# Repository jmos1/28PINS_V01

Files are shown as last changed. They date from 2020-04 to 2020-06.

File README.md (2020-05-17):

# 28Pins(Arduino) Project
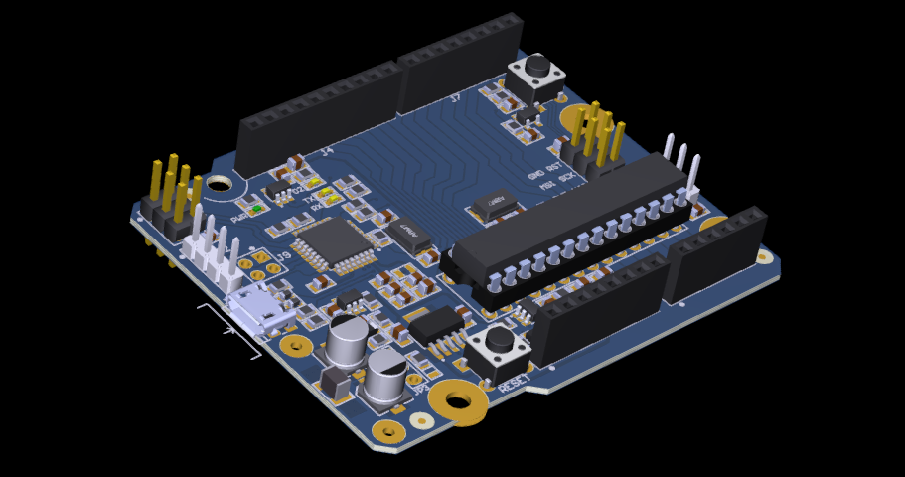
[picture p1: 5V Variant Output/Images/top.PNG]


### Summary: ###
  This project is one of two courses used to learn Altium Designer. It consists of a PCB that improves upon the Arduino Uno(Rev 3) design with better components and more features. You can find the link to this course at [Fedevel Academy](https://academy.fedevel.com/courses/online-want-to-design-your-own-arduino-board), and the repository of the other project [here](https://github.com/jmos1/ISL6236).

  The schematic PDF, 3D PCB PDF, and gerber files can all be accessed in the _'5V Variant Output/'_ folder. Other mechanical drawings are not included because they add clutter and can be generated from the project itself in Altium.
  
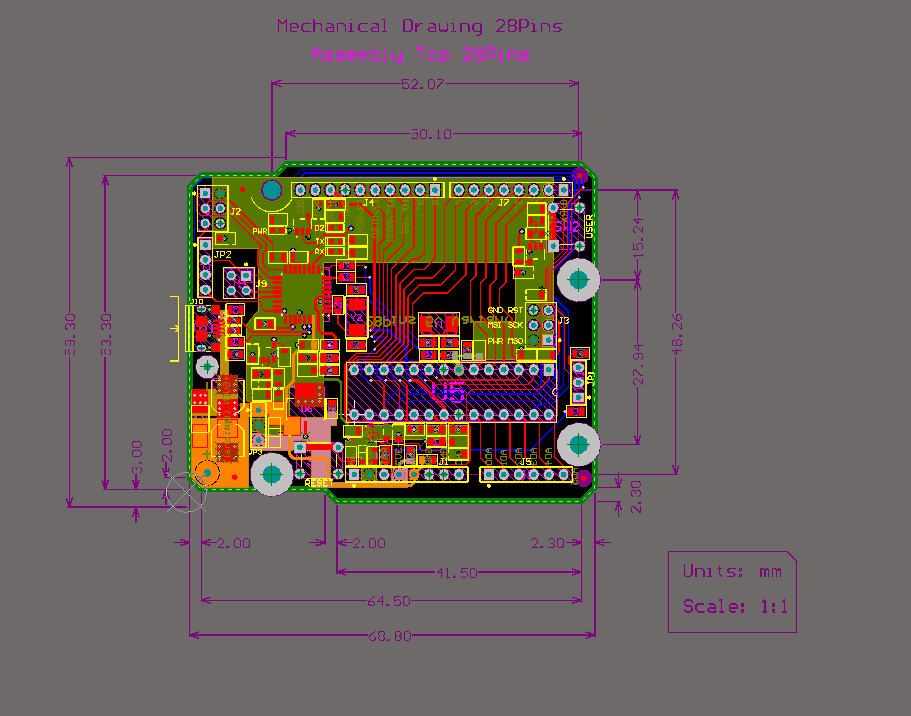
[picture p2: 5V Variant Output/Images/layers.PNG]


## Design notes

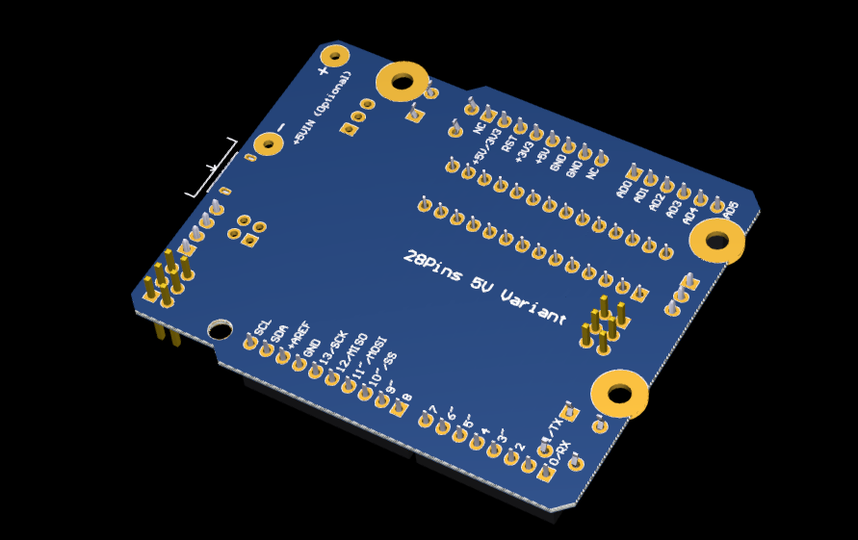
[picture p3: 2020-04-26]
5V Variant Output/Images/bottom.PNG

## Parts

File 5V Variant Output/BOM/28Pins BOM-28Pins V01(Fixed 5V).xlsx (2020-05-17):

Category | Description | LibRef | Manufacturer 1 | Manufacturer Part Number 1 | Package / Case | Package/Case | Quantity | Supplier 1 | Supplier Currency 1 | Supplier Order Qty 1 | Supplier Part Number 1 | Supplier Stock 1 | Supplier Subtotal 1 | Supplier Unit Price 1
Capacitors | TDK - C2012X7R1H104K085AA - Keramikvielschichtkondensator, SMD, 0.1 µF, 50 V, 0805 [Metrisch 2012], ± 10%, X7R, C Series TDK | C2012X7R1H104K085AA | TDK (https://octopart-clicks.com/click/altium?sku=445-7534-1-ND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) | C2012X7R1H104K085AA (https://octopart-clicks.com/click/altium?sku=445-7534-1-ND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) | 0805 (2012 Metric) |  | 19 | Digi-Key | USD | 190 | 445-7534-1-ND (https://octopart-clicks.com/click/altium?sku=445-7534-1-ND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) | 294092 | 10.659 | 0.0561
Capacitors | Automotive Grade MLCC, 0805, X5R, 16V, 10 F, 20%, 1.25mm | CGA4J1X5R1C106M125AC | TDK (https://octopart-clicks.com/click/altium?sku=445-12654-1-ND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) | CGA4J1X5R1C106M125AC (https://octopart-clicks.com/click/altium?sku=445-12654-1-ND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) | 0805 (2012 Metric) |  | 7 | Digi-Key | USD | 70 | 445-12654-1-ND (https://octopart-clicks.com/click/altium?sku=445-12654-1-ND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) | 6720 | 25.34 | 0.362
Capacitor Ceramic Multilayer | CAP CER 18PF 50V C0G/NP0 0805 | C0805C180J5GACTU | KEMET (https://octopart-clicks.com/click/altium?sku=399-1112-1-ND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) | C0805C180J5GACTU (https://octopart-clicks.com/click/altium?sku=399-1112-1-ND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) |  | 0805 | 4 | Digi-Key | USD | 40 | 399-1112-1-ND (https://octopart-clicks.com/click/altium?sku=399-1112-1-ND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) | 11617 | 4 | 0.1
Capacitors | CAP CER 1UF 25V X7R 0805 | CGA4J3X7R1E105K125AB | TDK (https://octopart-clicks.com/click/altium?sku=445-5687-1-ND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) | CGA4J3X7R1E105K125AB (https://octopart-clicks.com/click/altium?sku=445-5687-1-ND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) | 0805 (2012 Metric) |  | 1 | Digi-Key | USD | 10 | 445-5687-1-ND (https://octopart-clicks.com/click/altium?sku=445-5687-1-ND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) | 8402 | 1.63 | 0.163
 | Cap Aluminum 100uF 10V 20% (5 X 5.4mm) SMD 50mA 1000 hr 85°C T/R | EEE-1AA101WR | Panasonic (https://octopart-clicks.com/click/altium?sku=PCE3867CT-ND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) | EEE-1AA101WR (https://octopart-clicks.com/click/altium?sku=PCE3867CT-ND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) |  |  | 2 | Digi-Key | USD | 20 | PCE3867CT-ND (https://octopart-clicks.com/click/altium?sku=PCE3867CT-ND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) | 95730 | 4.42 | 0.221
Discrete Semiconductor Products | Schottky Diodes & Rectifiers SS SCHOTTKY DIODE | NSVBAT54HT1G | ON Semiconductor (https://octopart-clicks.com/click/altium?manufacturer=ON%20Semiconductor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) | NSVBAT54HT1G (https://octopart-clicks.com/click/altium?manufacturer=ON%20Semiconductor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) | SC-76, SOD-323 |  | 2 | Digi-Key | USD | 20 | NSVBAT54HT1GOSCT-ND (https://octopart-clicks.com/click/altium?manufacturer=ON%20Semiconductor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) | 10449 | 7.24 | 0.362
 | OSRAM - LO L29K-H2K1-24-Z - SMARTLED 0603 ORANGE | LOL29K-H2K1-24-Z | Osram Opto (https://octopart-clicks.com/click/altium?sku=475-2740-2-ND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) | LOL29K-H2K1-24-Z (https://octopart-clicks.com/click/altium?sku=475-2740-2-ND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) | 0603 (1608 Metric) |  | 3 | Digi-Key | Loading... |  | 475-2740-2-ND (https://octopart-clicks.com/click/altium?sku=475-2740-2-ND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) | 0
 | LED Uni-Color Green 572nm Automotive 2-Pin Chip 0603(1608Metric) T/R | LGL29K-F2J1-24-Z | Osram Opto (https://octopart-clicks.com/click/altium?sku=475-3118-1-ND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) | LGL29K-F2J1-24 (https://octopart-clicks.com/click/altium?sku=475-3118-1-ND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) | 0603 (1608 Metric) |  | 1 | Digi-Key | Loading... |  | 475-3118-1-ND (https://octopart-clicks.com/click/altium?sku=475-3118-1-ND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) | 0
Filters | FERRITE BEAD 600 OHM 0805 1LN | MPZ2012S601AT000 | TDK (https://octopart-clicks.com/click/altium?sku=445-2206-1-ND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) | MPZ2012S601AT000 (https://octopart-clicks.com/click/altium?sku=445-2206-1-ND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) | 0805 (2012 Metric) |  | 3 | Digi-Key | USD | 30 | 445-2206-1-ND (https://octopart-clicks.com/click/altium?sku=445-2206-1-ND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) | 208487 | 2.112 | 0.0704
Connector Headers and PCB Receptacles | 2.54mm (0.1") Pitch SIL Vertical PC Tail Socket Assembly, selective gold + tin, 8 contacts | M20-7820842 | Harwin (https://octopart-clicks.com/click/altium?sku=952-1823-ND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) | M20-7820842 (https://octopart-clicks.com/click/altium?sku=952-1823-ND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) |  |  | 2 | Digi-Key | USD | 20 | 952-1823-ND (https://octopart-clicks.com/click/altium?sku=952-1823-ND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) | 0 | 19.44 | 0.972
 | CONN HEADER VERT 6POS 2.54MM | 67997-206HLF | AMPHENOL ICC (FCI) (https://octopart-clicks.com/click/altium?manufacturer=AMPHENOL%20ICC%20%28FCI%29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) | 67997-206HLF (https://octopart-clicks.com/click/altium?manufacturer=AMPHENOL%20ICC%20%28FCI%29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) |  |  | 2 | Digi-Key | USD | 20 | 609-3234-ND (https://octopart-clicks.com/click/altium?manufacturer=AMPHENOL%20ICC%20%28FCI%29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) | 13697 | 6.32 | 0.316
 | HARWIN - M20-7821046 - Board-To-Board Connector, M20 Series, Through Hole, Receptacle, 10, 2.54 mm, Tin Plated Contacts | M20-7821046 | Harwin (https://octopart-clicks.com/click/altium?sku=952-1847-ND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) | M20-7821046 (https://octopart-clicks.com/click/altium?sku=952-1847-ND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) |  |  | 1 | Digi-Key | USD | 10 | 952-1847-ND (https://octopart-clicks.com/click/altium?sku=952-1847-ND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) | 497 | 11.22 | 1.122
Connector Headers and PCB Receptacles | Conn Socket Strip SKT 6 POS 2.54mm Solder ST Thru-Hole Tube | M20-7820642 | Harwin (https://octopart-clicks.com/click/altium?sku=952-1808-ND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) | M20-7820642 (https://octopart-clicks.com/click/altium?sku=952-1808-ND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) |  |  | 1 | Digi-Key | USD | 10 | 952-1808-ND (https://octopart-clicks.com/click/altium?sku=952-1808-ND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) | 1115 | 8.7 | 0.87
 | CONN USB MICRO B RECPT SMT R/A | 10118193-0001LF | Amphenol ICC (https://octopart-clicks.com/click/altium?sku=609-4616-1-ND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) | 10118193-0001LF (https://octopart-clicks.com/click/altium?sku=609-4616-1-ND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) |  |  | 1 | Digi-Key | USD | 10 | 609-4616-1-ND (https://octopart-clicks.com/click/altium?sku=609-4616-1-ND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) | 47097 | 4.05 | 0.405
 | CONN HEADER VERT 3POS 2.54MM | 68000-203HLF | AMPHENOL ICC (FCI) (https://octopart-clicks.com/click/altium?manufacturer=AMPHENOL%20ICC%20%28FCI%29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) | 68000-203HLF (https://octopart-clicks.com/click/altium?manufacturer=AMPHENOL%20ICC%20%28FCI%29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) |  |  | 1 | Digi-Key | USD | 10 | 609-3464-ND (https://octopart-clicks.com/click/altium?manufacturer=AMPHENOL%20ICC%20%28FCI%29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) | 14255 | 2.67 | 0.267
Connector Headers and PCB Receptacles | CONN HEADER VERT 4POS 2.54MM | 68001-204HLF | Amphenol FCI (https://octopart-clicks.com/click/altium?sku=609-3402-ND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) | 68001-204HLF (https://octopart-clicks.com/click/altium?sku=609-3402-ND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) |  |  | 1 | Digi-Key | USD | 10 | 609-3402-ND (https://octopart-clicks.com/click/altium?sku=609-3402-ND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) | 3820 | 3.57 | 0.357
 | FIXED IND 2.2UH 2A 80 MOHM SMD | L1210R2R2MDWIT | KEMET (https://octopart-clicks.com/click/altium?sku=399-9598-1-ND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) | L1210R2R2MDWIT (https://octopart-clicks.com/click/altium?sku=399-9598-1-ND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) |  | 1210 | 1 | Digi-Key | USD | 10 | 399-9598-1-ND (https://octopart-clicks.com/click/altium?sku=399-9598-1-ND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) | 19953 | 4.79 | 0.479
Connectors, Interconnects | CONN JUMPER SHORTING .100" GOLD | QPC02SXGN-RC | Sullins (https://octopart-clicks.com/click/altium?sku=S9337-ND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) | QPC02SXGN-RC (https://octopart-clicks.com/click/altium?sku=S9337-ND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) |  |  | 2 | Digi-Key | USD | 20 | S9337-ND (https://octopart-clicks.com/click/altium?sku=S9337-ND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) | 713549 | 1.18 | 0.059
 | Surface Mount Thick Film Resistor, RC Series, 560 ohm, 125 mW, - 1%, 150 V, 0805 [2012 Metric] | RC0805FR-07560RL | Yageo (https://octopart-clicks.com/click/altium?sku=311-560CRCT-ND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) | RC0805FR-07560RL (https://octopart-clicks.com/click/altium?sku=311-560CRCT-ND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) | 0805 (2012 metric) |  | 5 | Digi-Key | USD | 50 | 311-560CRCT-ND (https://octopart-clicks.com/click/altium?sku=311-560CRCT-ND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) | 290519 | 2 | 0.04
 | RES SMD 10K OHM 1% 1/8W 0805 | RC0805FR-0710KL | Yageo (https://octopart-clicks.com/click/altium?sku=311-10.0KCRCT-ND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) | RC0805FR-0710KL (https://octopart-clicks.com/click/altium?sku=311-10.0KCRCT-ND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) |  |  | 6 | Digi-Key | USD | 60 | 311-10.0KCRCT-ND (https://octopart-clicks.com/click/altium?sku=311-10.0KCRCT-ND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) | 23588125 | 2.4 | 0.04
 | RESISTOR, 0805 1K 1%, FULL REEL; Product Range:YAGEO - RC Series; Resistance:1kohm; Power Rating:125mW; Resistance Tolerance:± 1%; Resistor Case Style:0805 [2012 Metric]; Resistor Element Material:Thick Film; Temperature Coefficient:± 250ppm/°C; Voltage Rating:150V; Packaging:Tape & Reel; MSL:-; SVHC:No SVHC (16-Dec-2013); External Depth:0.55mm; External Length / Height:2mm; External Width:1.25mm; No. of Pins:2; Operating Temperature Max:155°C; Operating Temperature Min:-55°C; Operating Temperature Range:-55°C to +155°C; Reel Quantity:5000; Resistor Mounting:SMD; Series:RC12H; Temperature Coef | RC0805FR-071KL | Yageo (https://octopart-clicks.com/click/altium?sku=311-1.00KCRCT-ND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) | RC0805FR-071KL (https://octopart-clicks.com/click/altium?sku=311-1.00KCRCT-ND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) |  |  | 3 | Digi-Key | USD | 30 | 311-1.00KCRCT-ND (https://octopart-clicks.com/click/altium?sku=311-1.00KCRCT-ND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) | 20780074 | 1.2 | 0.04
 | RES SMD 22 OHM 1% 1/8W 0805 | AC0805FR-0722RL | Yageo (https://octopart-clicks.com/click/altium?sku=YAG3713CT-ND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) | AC0805FR-0722RL (https://octopart-clicks.com/click/altium?sku=YAG3713CT-ND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) | 0805 (2012 metric) |  | 7 | Digi-Key | USD | 70 | YAG3713CT-ND (https://octopart-clicks.com/click/altium?sku=YAG3713CT-ND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) | 1995 | 3.36 | 0.048
 | Surface Mount Thick Film Resistor, RC Series, 125 mW, - 5%, 150 V, 0805 [2012 Metric] | RC0805JR-070RL | Yageo (https://octopart-clicks.com/click/altium?sku=311-0.0ARCT-ND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) | RC0805JR-070RL (https://octopart-clicks.com/click/altium?sku=311-0.0ARCT-ND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) |  |  | 2 | Digi-Key | USD | 20 | 311-0.0ARCT-ND (https://octopart-clicks.com/click/altium?sku=311-0.0ARCT-ND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) | 8922209 | 0.7 | 0.035
 | RES SMD 1M OHM 1% 1/8W 0805 | RC0805FR-071ML | Yageo Phycomp (https://octopart-clicks.com/click/altium?sku=311-1.00MCRCT-ND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) | RC0805FR-071ML (https://octopart-clicks.com/click/altium?sku=311-1.00MCRCT-ND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) |  |  | 2 | Digi-Key | USD | 20 | 311-1.00MCRCT-ND (https://octopart-clicks.com/click/altium?sku=311-1.00MCRCT-ND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) | 3769891 | 0.8 | 0.04
 | YAGEO RC0805FR-07100KL RES, THICK FILM, 100K, 1%, 0.125W, 0805, REEL | RC0805FR-07100KL | Yageo (https://octopart-clicks.com/click/altium?sku=311-100KCRDKR-ND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) | RC0805FR-07100KL (https://octopart-clicks.com/click/altium?sku=311-100KCRDKR-ND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) |  |  | 1 | Digi-Key | USD | 10 | 311-100KCRDKR-ND (https://octopart-clicks.com/click/altium?sku=311-100KCRDKR-ND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) | 5167697 | 0.4 | 0.04
 | CONN IC DIP SOCKET 28POS TIN | 4828-3004-CP | 3M (https://octopart-clicks.com/click/altium?sku=3M5480-ND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) | 7010501790 (https://octopart-clicks.com/click/altium?sku=3M5480-ND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) |  |  | 1 | Digi-Key | USD | 10 | 3M5480-ND (https://octopart-clicks.com/click/altium?sku=3M5480-ND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) | 4924 | 6.93 | 0.693
 | ALCOSWITCH - TE CONNECTIVITY - 1825910-6 - Tactile Switch, FSMJ Series, Top Actuated, Through Hole, Round Button, 160 gf, 50mA at 24VDC | 1825910-6 | ALCOSWITCH - TE CONNECTIVITY (https://octopart-clicks.com/click/altium?manufacturer=ALCOSWITCH%20-%20TE%20CONNECTIVITY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) | 1825910-6 (https://octopart-clicks.com/click/altium?manufacturer=ALCOSWITCH%20-%20TE%20CONNECTIVITY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) |  |  | 2 | Digi-Key | USD | 20 | 450-1650-ND (https://octopart-clicks.com/click/altium?manufacturer=ALCOSWITCH%20-%20TE%20CONNECTIVITY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) | 19110 | 2.02 | 0.101
Integrated Circuits (ICs) | TEXAS INSTRUMENTS - SN74AHC1G09DBVR - AND Gate, 74AHC1G09, 2 Input, 2 V to 5.5 V, SOT-23-5 | SN74AHC1G09DBVR | Texas Instruments (https://octopart-clicks.com/click/altium?sku=296-29202-1-ND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) | SN74AHC1G09DBVR (https://octopart-clicks.com/click/altium?sku=296-29202-1-ND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) | SC-74A, SOT-753 |  | 4 | Digi-Key | USD | 40 | 296-29202-1-ND (https://octopart-clicks.com/click/altium?sku=296-29202-1-ND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) | 16072 | 8.4 | 0.21
 | ATMEGA328P-PU; 8 bit Microcontroller AVR 20MHz 1; 32kb Flash; 2kb RAM; I2C SPI 2 | ATMEGA328P-PU | Microchip / Atmel (https://octopart-clicks.com/click/altium?manufacturer=Microchip%20%2F%20Atmel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) | ATMEGA328P-PU (https://octopart-clicks.com/click/altium?manufacturer=Microchip%20%2F%20Atmel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) |  |  | 1 | Digi-Key | USD | 10 | ATMEGA328P-PU-ND (https://octopart-clicks.com/click/altium?manufacturer=Microchip%20%2F%20Atmel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) | 500 | 20.8 | 2.08
Integrated Circuits (ICs) | Single Output LDO, 1.5A, 3.3V Fast Trans | TL1963A-33DCQT | Texas Instruments (https://octopart-clicks.com/click/altium?sku=296-32342-1-ND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) | TL1963A-33DCQT (https://octopart-clicks.com/click/altium?sku=296-32342-1-ND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) | SOT-223-6 |  | 1 | Digi-Key | USD | 10 | 296-32342-1-ND (https://octopart-clicks.com/click/altium?sku=296-32342-1-ND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) | 286 | 28.27 | 2.827
 | MICROCHIP - ATMEGA16U2-AU - MCU, 8BIT, MEGAAVR, 16MHZ, TQFP-32 | ATMEGA16U2-AU | Microchip / Atmel (https://octopart-clicks.com/click/altium?manufacturer=Microchip%20%2F%20Atmel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) | ATMEGA16U2-AU (https://octopart-clicks.com/click/altium?manufacturer=Microchip%20%2F%20Atmel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) |  |  | 1 | Digi-Key | USD | 10 | ATMEGA16U2-AU-ND (https://octopart-clicks.com/click/altium?manufacturer=Microchip%20%2F%20Atmel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) | 1508 | 24.5 | 2.45
Crystals and Oscillators | CRYSTAL 16.0000MHZ 18PF SMD | ABM7-16.000MHZ-D2Y-T | Abracon (https://octopart-clicks.com/click/altium?sku=535-9840-1-ND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) | ABM7-16.000MHZ-D2Y-T (https://octopart-clicks.com/click/altium?sku=535-9840-1-ND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) | 2-SMD |  | 2 | Digi-Key | USD | 20 | 535-9840-1-ND (https://octopart-clicks.com/click/altium?sku=535-9840-1-ND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) | 66828 | 17.72 | 0.886
 | ESD Suppressor TVS Bi-Dir 5V Automotive 2-Pin Case 0603(1608Metric) T/R | CGA0603MLC-05E | Bourns (https://octopart-clicks.com/click/altium?sku=CGA0603MLC-05ECT-ND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) | CGA0603MLC-05E (https://octopart-clicks.com/click/altium?sku=CGA0603MLC-05ECT-ND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) |  |  | 2 | Digi-Key | USD | 20 | CGA0603MLC-05ECT-ND (https://octopart-clicks.com/click/altium?sku=CGA0603MLC-05ECT-ND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) | 4615 | 7.34 | 0.367

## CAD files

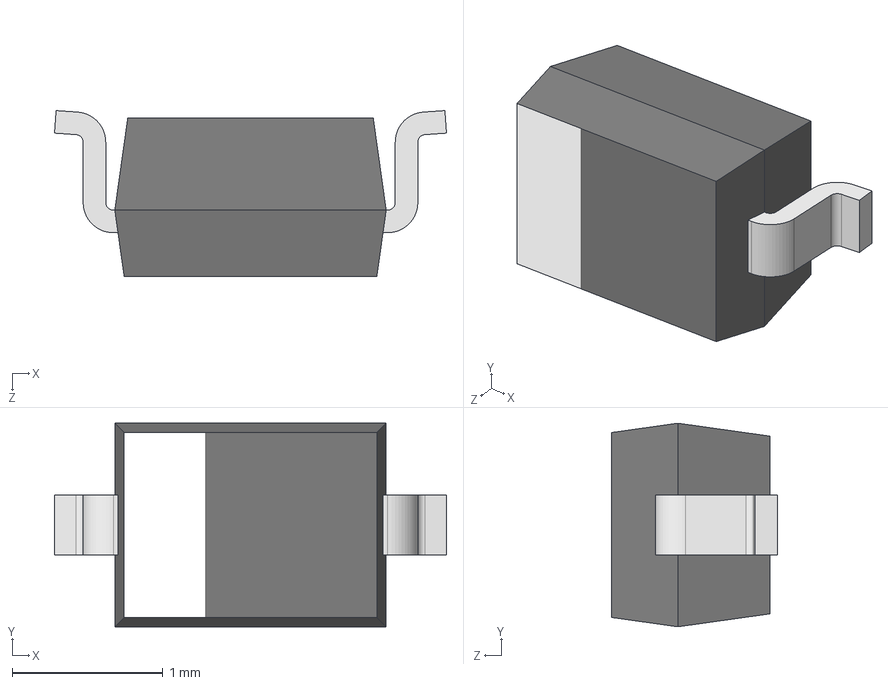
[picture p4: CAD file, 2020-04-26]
3D Models/SOD323.step
2.60 x 1.35 x 1.10 mm

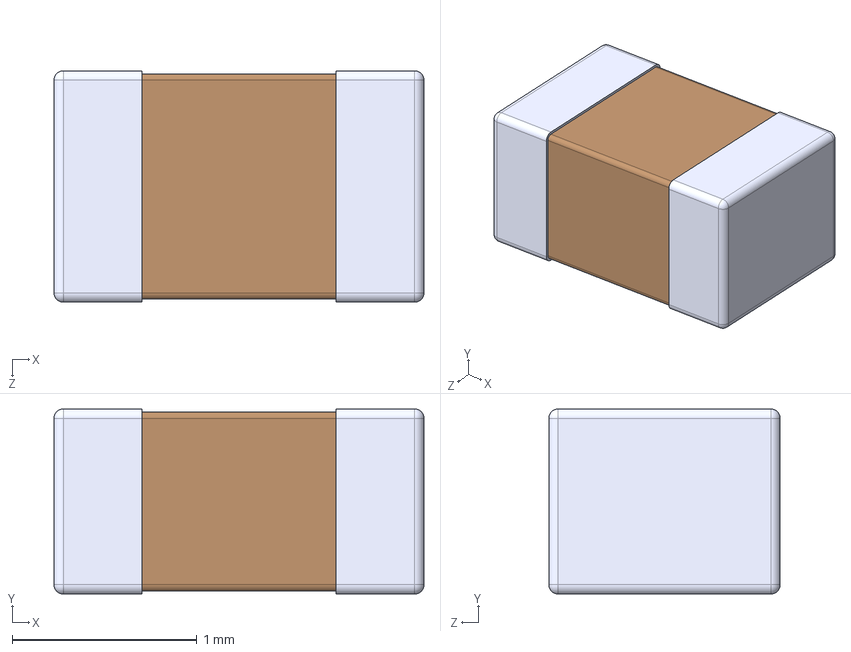
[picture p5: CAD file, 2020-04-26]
3D Models/c0805.STEP
2.00 x 1.00 x 1.25 mm

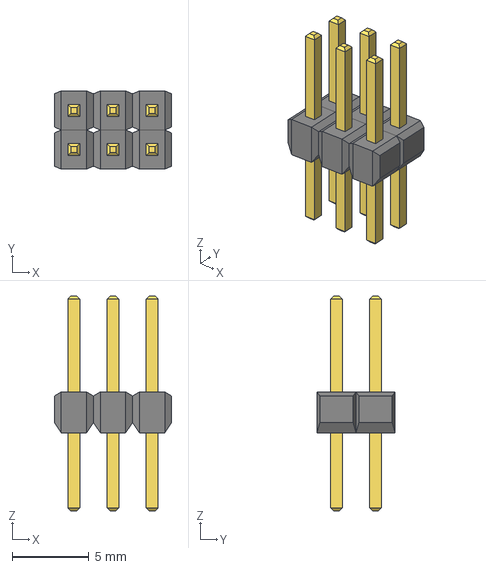
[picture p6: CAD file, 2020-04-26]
3D Models/hdr_male_2x6_2.54.step
7.62 x 5.08 x 14.0 mm

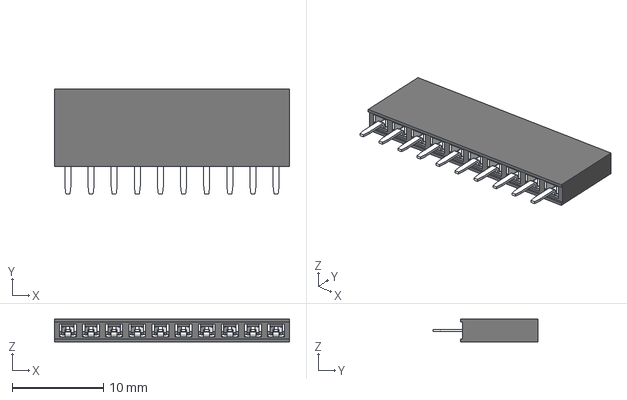
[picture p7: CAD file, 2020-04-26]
3D Models/hdr_female_1x10_2.54.stp
25.8 x 11.5 x 2.50 mm
M20-78210_MOULD
M20-782_CONTACT x 10

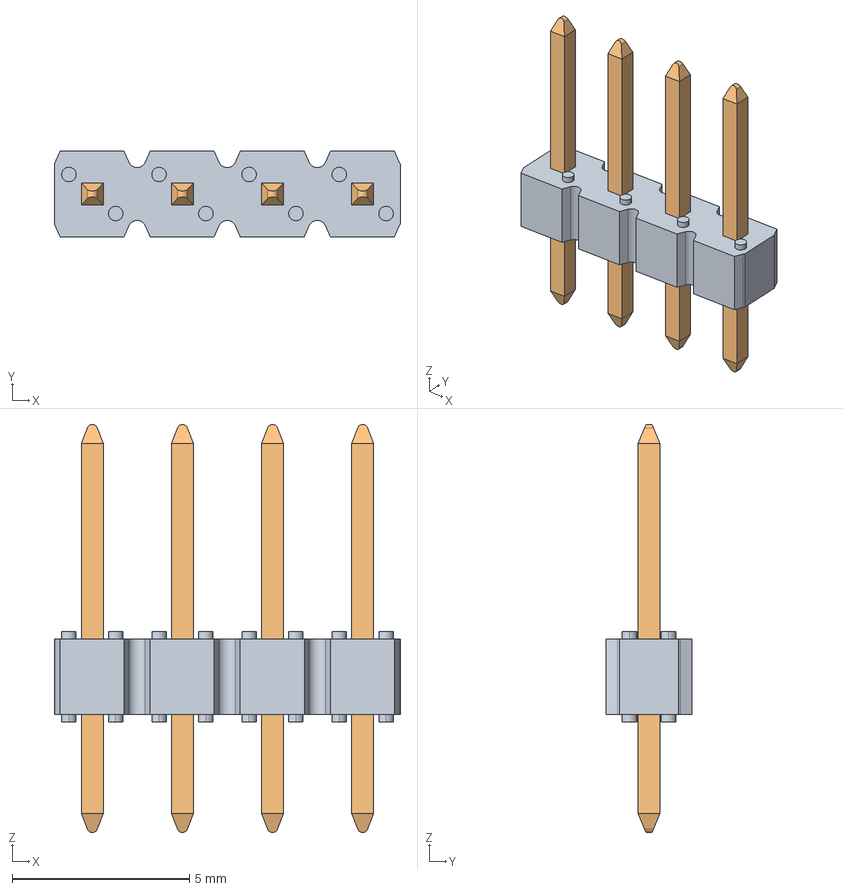
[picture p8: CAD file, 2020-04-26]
3D Models/HDR_1x4_White.stp
9.76 x 2.41 x 11.5 mm

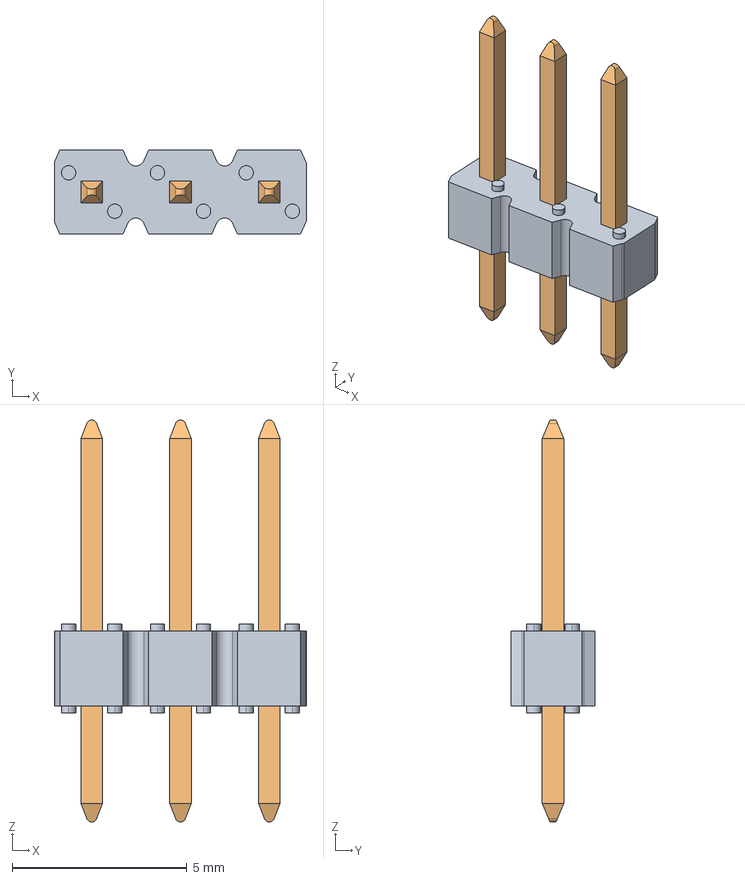
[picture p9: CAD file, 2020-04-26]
3D Models/HDR_1x3_White.stp
7.22 x 2.41 x 11.5 mm
77310_Y16 x 3

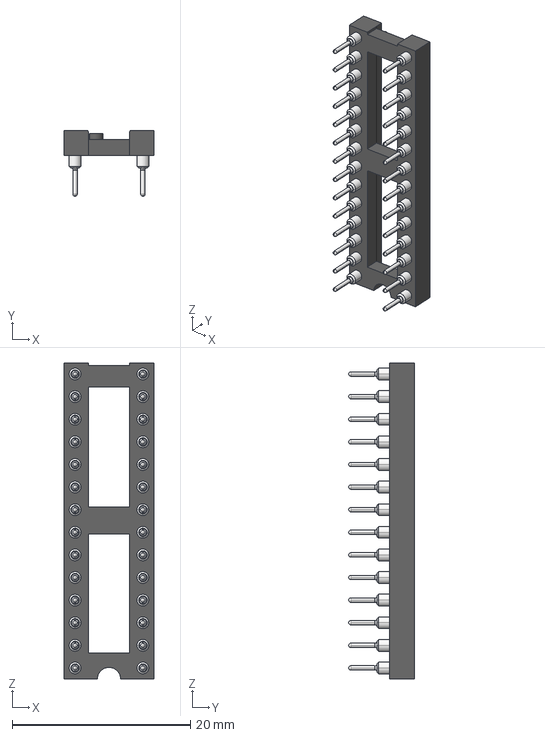
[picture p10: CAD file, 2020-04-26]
3D Models/dip_28_socket.stp
10.1 x 7.37 x 35.5 mm

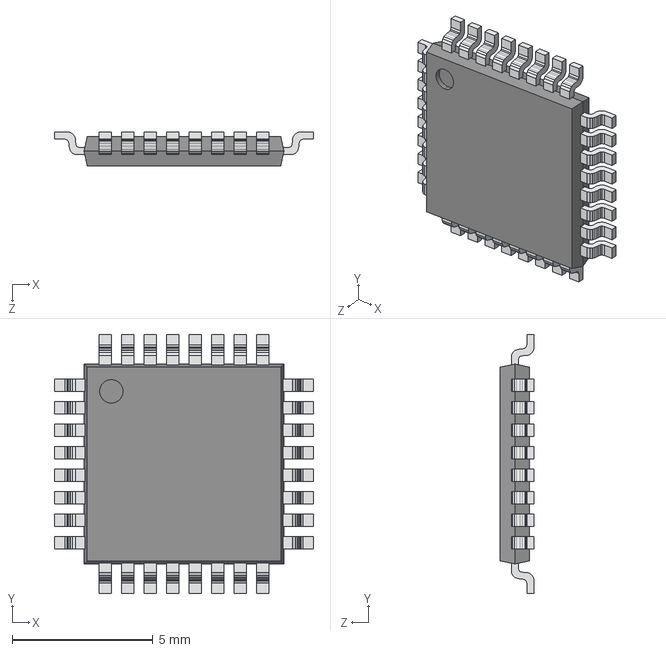
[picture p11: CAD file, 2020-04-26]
3D Models/tqfp32.step
9.20 x 9.20 x 1.20 mm

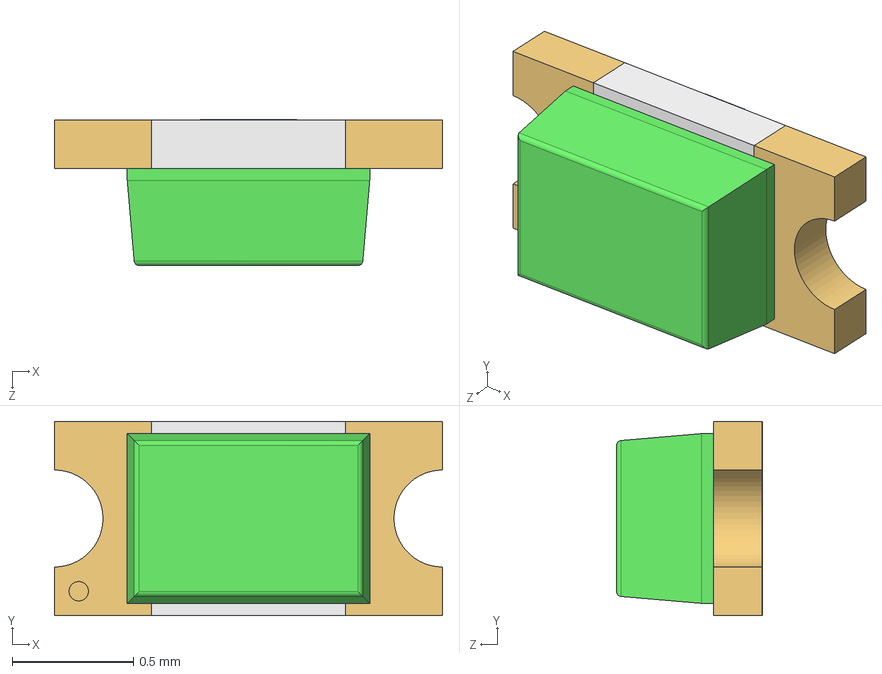
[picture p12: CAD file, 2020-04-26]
3D Models/LED_0603_Green.STEP
1.60 x 0.8 x 0.602 mm

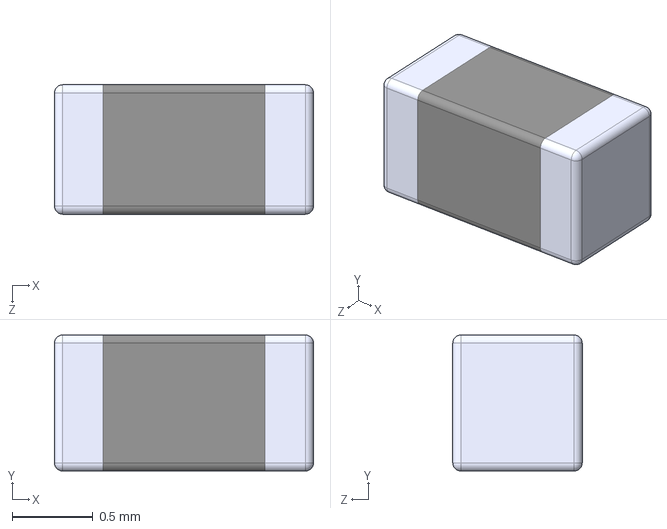
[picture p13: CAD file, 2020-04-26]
3D Models/R0603.step
1.60 x 0.84 x 0.8 mm

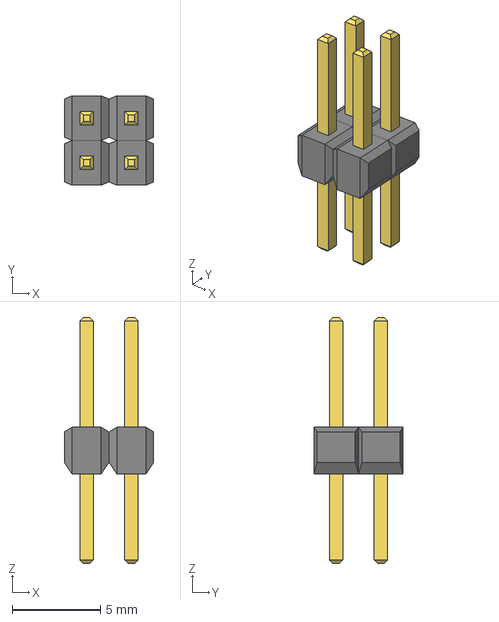
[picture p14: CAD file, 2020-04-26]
3D Models/hdr_male_2x2_2.54.step
5.08 x 5.08 x 14.0 mm

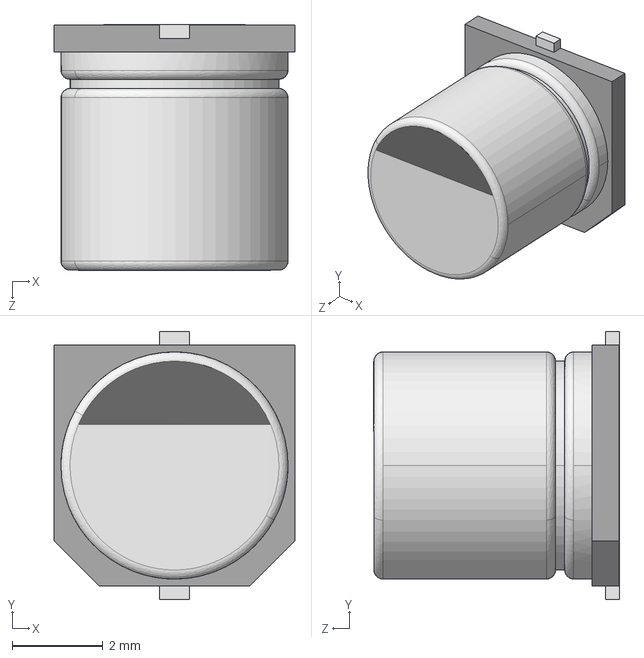
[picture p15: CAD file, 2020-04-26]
3D Models/cap_alu_c.step
5.30 x 5.90 x 5.41 mm

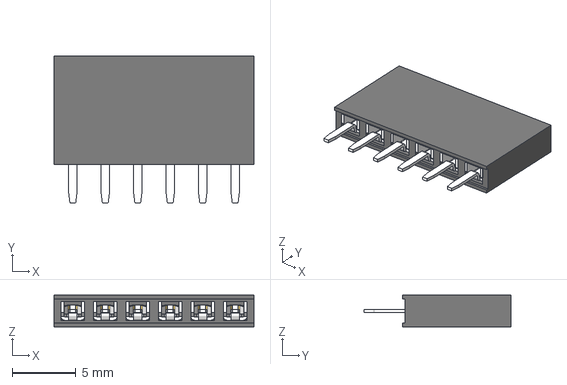
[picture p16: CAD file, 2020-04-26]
3D Models/hdr_female_1x6_2.54.stp
15.6 x 11.5 x 2.50 mm
M20-78206_MOULD
M20-782_CONTACT x 6

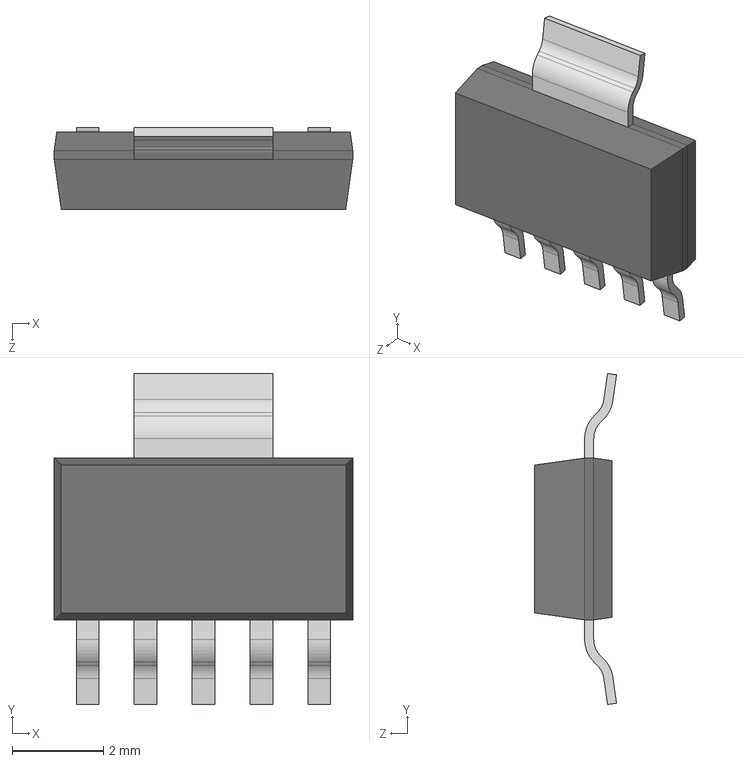
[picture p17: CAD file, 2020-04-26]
3D Models/TL1963ADCQR_SOT223-6.step
6.55 x 7.26 x 1.80 mm

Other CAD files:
3D Models/LED_0603_Orange.STEP
3D Models/c0805_1.25mm_height.STEP
3D Models/ABM7.STEP
3D Models/sw_1825910-6.step
3D Models/TPS79333DBVR.step
3D Models/dip_28.step
3D Models/hdr_female_1x8_2.54.stp
3D Models/r0805.STEP
3D Models/usb_micro_female.STEP

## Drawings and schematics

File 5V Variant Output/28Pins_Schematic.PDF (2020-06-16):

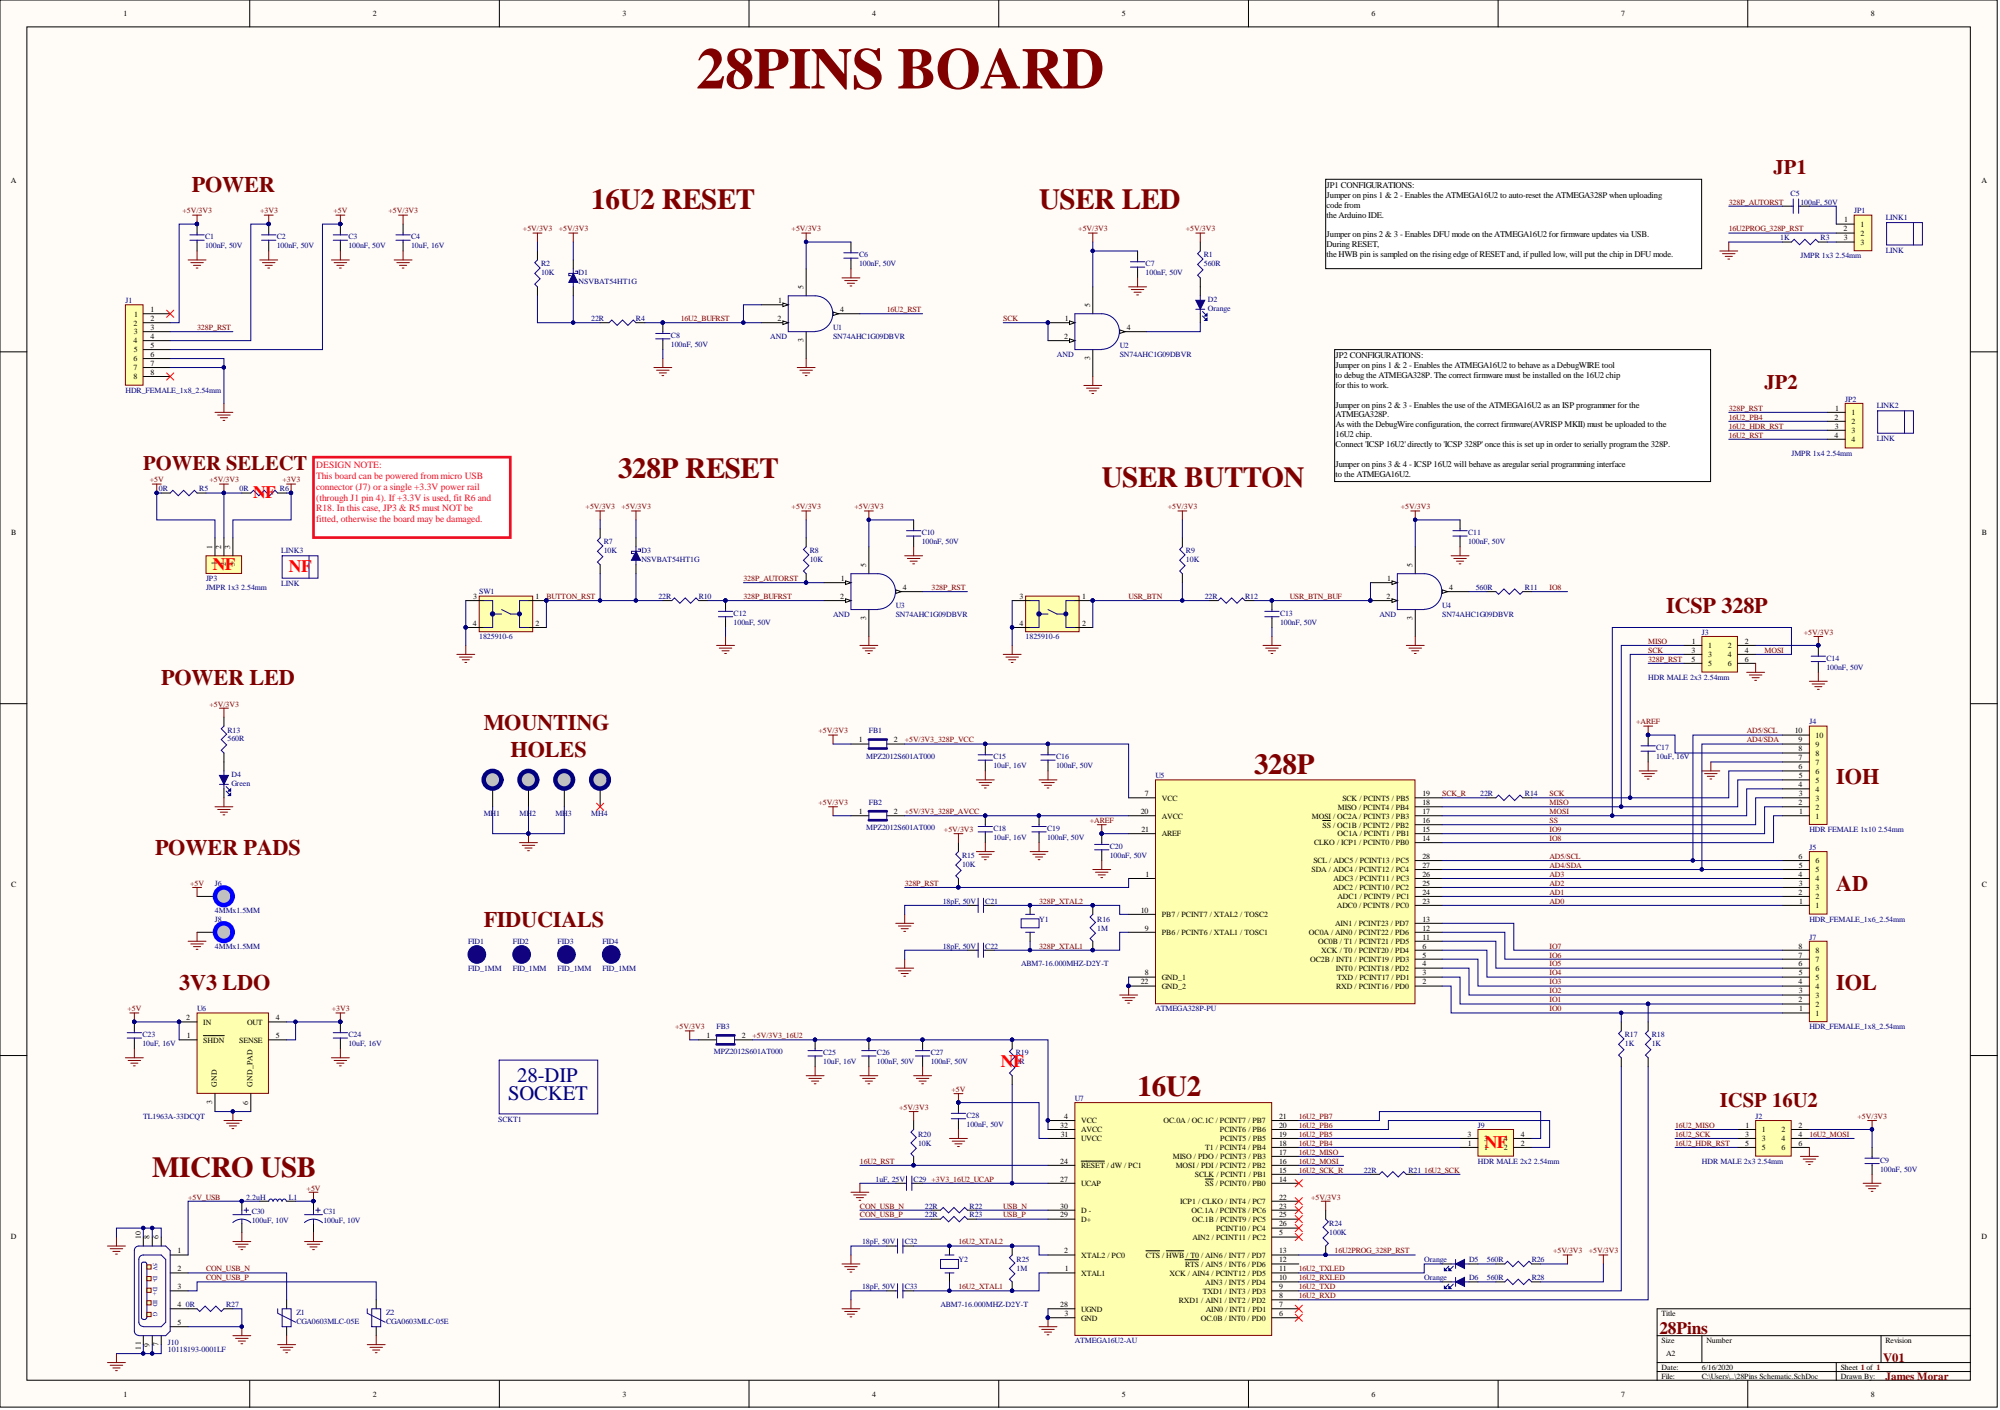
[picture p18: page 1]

JP1 CONFIGURATIONS:
Jumper on pins 1 & 2 - Enables the ATMEGA16U2 to auto-reset the ATMEGA328P when uploading
code from
the Arduino IDE.

Jumper on pins 2 & 3 - Enables DFU mode on the ATMEGA16U2 for firmware updates via USB.
During RESET,
the HWB pin is sampled on the rising edge of RESET and, if pulled low, will put the chip in DFU mode.

JP2 CONFIGURATIONS:
Jumper on pins 1 & 2 - Enables the ATMEGA16U2 to behave as a DebugWIRE tool
to debug the ATMEGA328P. The correct firmware must be installed on the 16U2 chip
for this to work.

Jumper on pins 2 & 3 - Enables the use of the ATMEGA16U2 as an ISP programmer for the
ATMEGA328P.
As with the DebugWire configuration, the correct firmware(AVRISP MKII) must be uploaded to the
16U2 chip.
Connect 'ICSP 16U2' directly to 'ICSP 328P' once this is set up in order to serially program the 328P.

DESIGN NOTE:
This board can be powered from micro USB
connector (J7) or a single +3.3V power rail
(through J1 pin 4). If +3.3V is used, fit R6 and
R18. In this case, JP3 & R5 must NOT be
fitted, otherwise the board may be damaged.

Jumper on pins 3 & 4 - ICSP 16U2 will behave as aregular serial programming interface
to the ATMEGA16U2.

C17 | AD4/SDA

SCK_R 22R R14 | SCK

AVCC 20 | | MISO

AREF 21 | | SS

PC6 / PCINT14 / RESET 1 | | IO8

AD5/SCL
AD4/SDA

IO7
IO6

GND_2 22 | IO3

IO2
IO1
IO0

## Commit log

2020-04-26 Initial test upload
    [28Pins Schematic.SchDoc, 28Pins V01.PcbLib, 28Pins V01.PrjPcb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]
2020-05-17 Cleaned up project
    [28Pins PCB V01.GBL, 28Pins PCB V01.GBO, 28Pins PCB V01.GBP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]
2020-05-17 Added BOM
    [28Pins BOM-28Pins V01(Fixed 5V).xlsx]
2020-06-16 Mechanical drawing modifications and schematic modifications
    [28Pins Schematic.SchDoc]
